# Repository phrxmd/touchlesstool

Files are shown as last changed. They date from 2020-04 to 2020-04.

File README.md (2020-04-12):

# touchlesstool

A customizable, parametric 3D design for a "truly touchless" no-touch
tool, designed to allow opening doors, pushing buttons etc. without
coming into direct physical contact with the surfaces. The tool is
"truly touchless" in the sense that the tool itself, which potentially
could be contaminated with material from the surfaces it touches, is
normally hidden in a sleeve and protected from accidental touches by the
user.

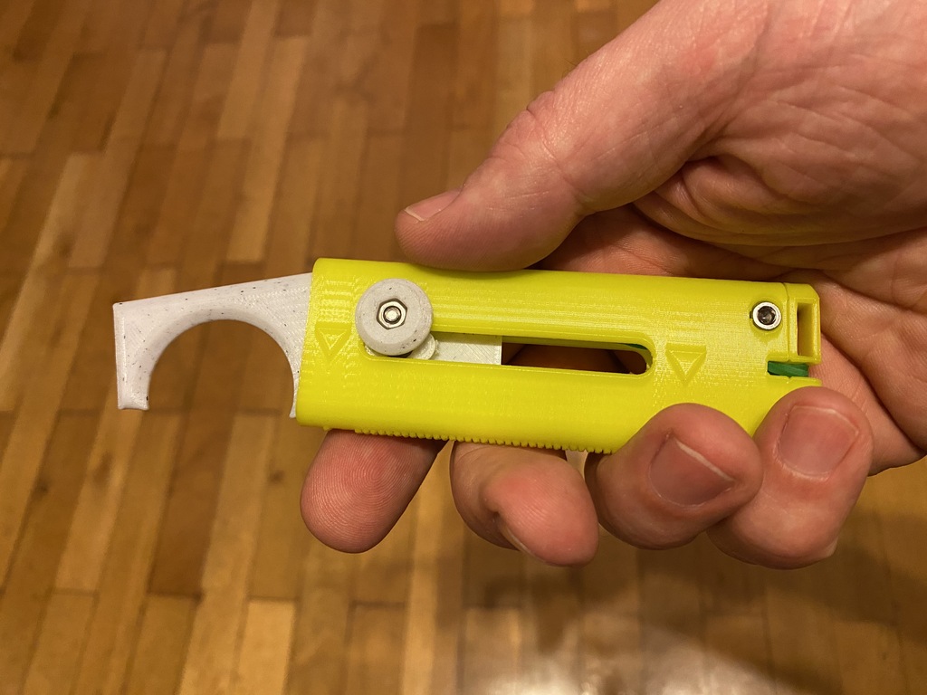
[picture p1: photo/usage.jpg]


The model is almost totally parametric, so you can change everything -
make it taller or wider, change some functionality, use different means
of attachment, generate different quality - by changing variables in the
SCAD file.

STLs for printing can be found in the `stl` subdirectory, on Thingiverse
(<https://www.thingiverse.com/thing:4266457>) and on PrusaPrinters
(<https://www.prusaprinters.org/prints/28714-truly-touchless-parametric-no-touch-tool>).

# Usage, printing and assembly

## Usage

Use the tool to open doors, push buttons or pick-up objects without
touching them with your hand. Extend the tool by pushing the knob with
your fingers. You can lock the tool in its extended state by moving the
knob sideways into the diagonal slot.

In daily use, you can attch the tool to your pants, belt or pocket using
a lanyard or an extensible "badge yo-yo". The end cap has a slot for
attaching it.

The tool should offer the user some protection against accidental touch
infection by means of its design. However, users may want to disinfect
it. For disinfection, the tool blade can be rinsed in alcohol or any
sterilizing liquid, or wiped off with a suitable substance, depending on
your context. If you want to be able to sterilize the tool, make sure to
print it with a material that quite literally can take the heat. Common
materials like PLA and PETG are not heat-resistant enough.

## Printing

The model is quite print-friendly in the default configuration. There
are no great overhangs or structures that require support - the longest
is a 10mm slot in the endcap. The tool sleeve should be printed
standing, so it may require some adhesion structures (like a brim or
raft). I usually print the sleeve on a raft, and the other structures
"as is".

Recommended print settings are: layer height 0.2, infill 25-30%, infill
pattern "cuboid" (in Cura) or something similar that gives rigidity in
all directions, and whatever temperature and flow settings match your
filament.

## Assembly of printed parts

In the default configuration, assembly requires the following parts:

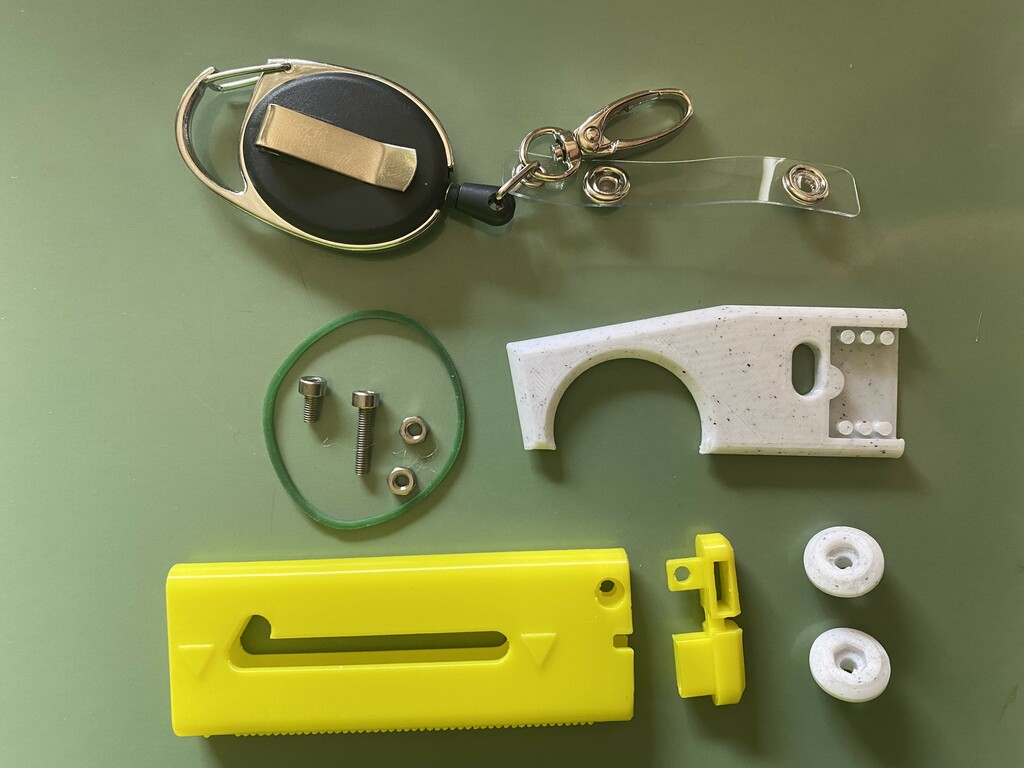
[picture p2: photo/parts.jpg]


1.  Printed parts
    1.  Printed tool body (with the hook and central bolt hole)
    2.  Printed sleeve (with the central slot)
    3.  Printed endcap
    4.  Printed bolt
2.  Other parts ("vitamins" in RepRap parlance)
    1.  Two bolts M3x6 and M3x14 (or minimally longer).
    2.  Two hex nuts.
    3.  A rubber band (short-ish is better).
3.  Optional parts
    1.  A lanyard or "badge yo-yo" for attaching the tool to your belt
        or pocket.

These are the steps for assembly:

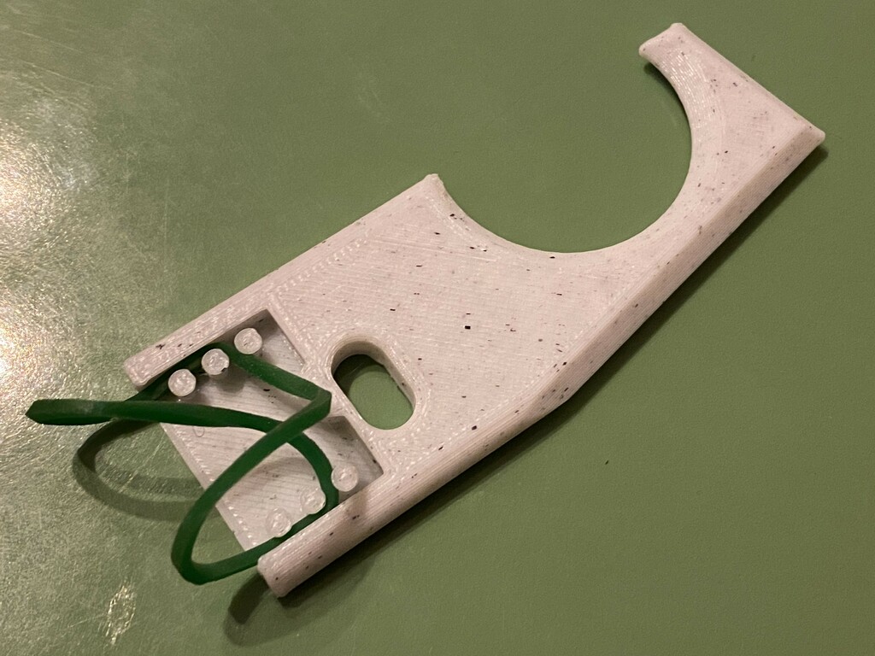
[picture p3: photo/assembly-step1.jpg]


Thread the rubber band into the body on both sides. The body has a
cavity at the bottom with rows of posts that are meant for this purpose.
Find a configuration where your rubber band extends in at least one loop
below the body for 1-2 cm (not longer).

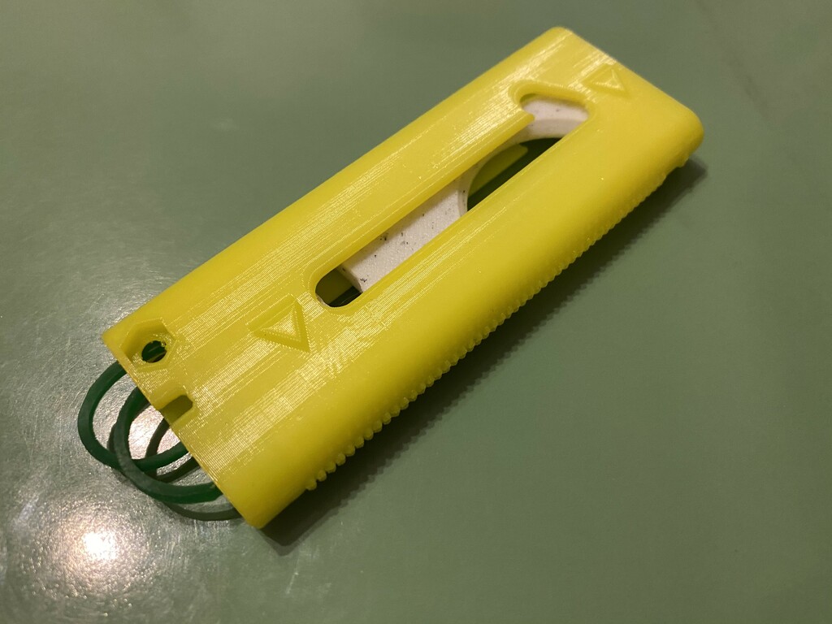
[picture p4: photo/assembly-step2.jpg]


Thread the body and rubber band into the sleeve from the top. The sleeve
has raised triangles above and below the slots; this is the direction
where the tip of the tool should point. Then pull the loop end of the
rubber through the bottom of the sleeve. Use a paperclip or similar if
it gets fiddly, which it probably will.

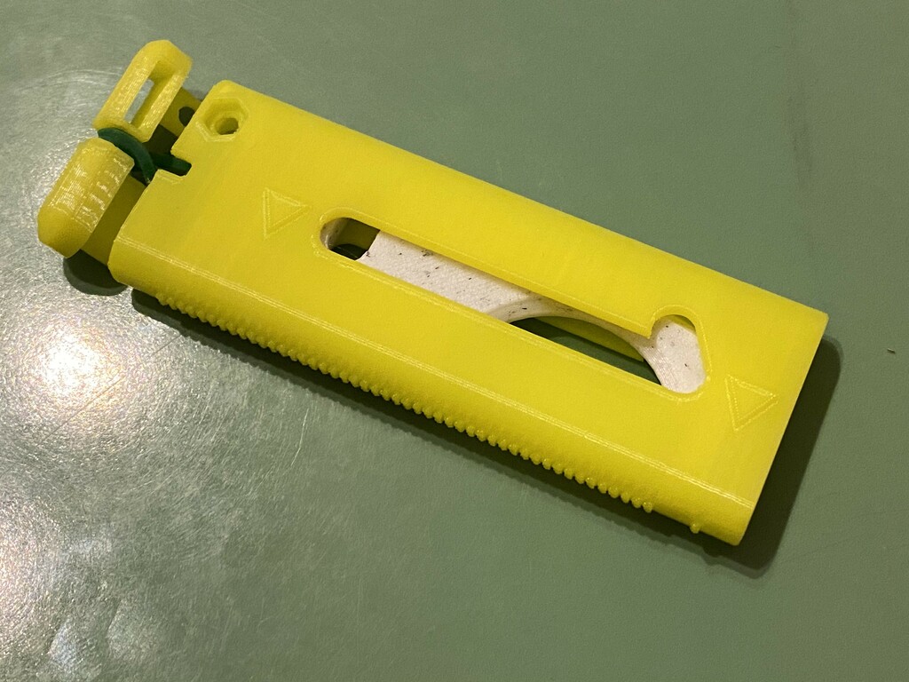
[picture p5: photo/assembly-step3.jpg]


Put the end cap into the rubber loop so that the rubber strands run in
the groove around the endcap, and attach the endcap to the sleeve. It
should sit snugly, and the rubber should not be too loose. Screw the
endcap into the body using an M3x6 bolt and a hex nut.

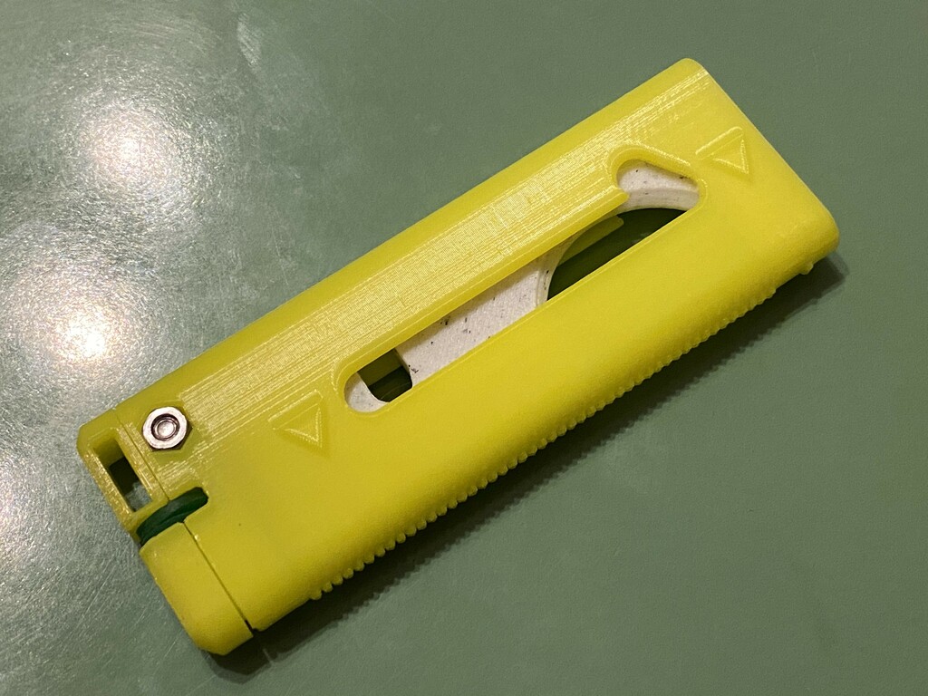
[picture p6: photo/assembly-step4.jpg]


Insert an M3x14 bolt and hex nut into the two parts of the printed
central bolt, and attach them through the central hole.

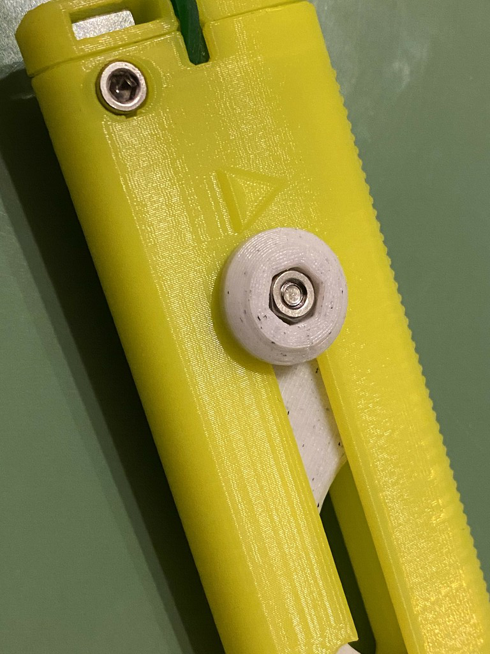
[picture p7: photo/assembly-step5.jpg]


(optional) Thread your lanyard through the slot in the endcap.

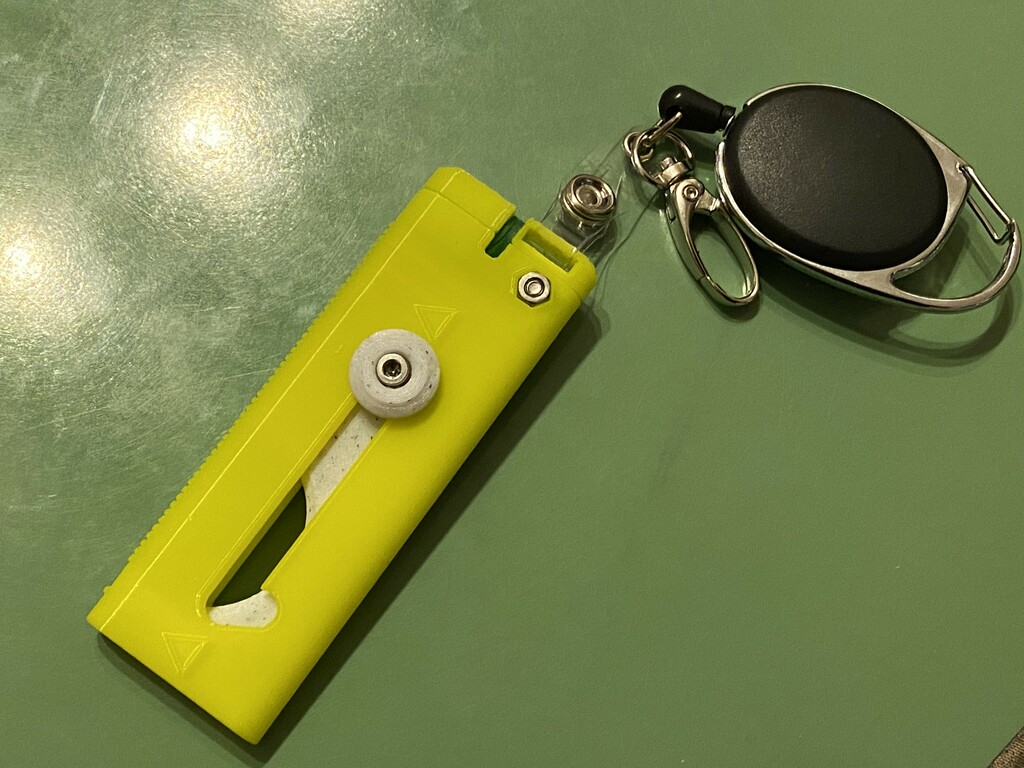
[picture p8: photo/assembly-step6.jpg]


That's it\!

# Customization

The model was written in SCAD and is parametric and highly customizable.
It is designed with 3D printing in mind. Open it in
[OpenSCAD](https://www.openscad.org) to see the configuration options
and generate STL files for printing.

## Common customization use cases

In the default configuration, the model generates an STL file with all
the parts for a tool that is about 9.5 by 3.5 by 1 cm, held together by
M3 bolts.

### Generating only some parts, or separate parts

This is a FAQ item. In the SCAD file, there are a set of configuration
items in the beginning that allow you to specify which parts of the
model to generate. You can set them to `true` one by one to generate
STLs for the parts you need.

### A model with no lanyard slot, or with a hole for a keyring

Set `ATTACHMENT_STYLE` to `none` or `hole` instead of the default
`slot`. The diameter of the keyring hole is set by `CAP_HOLE_DIA`, the
default is 5mm. If you add a keyring hole, you might also need to
increase `CAP_HEIGHT` and/or lower `CAP_CHAMFER`, to make sure that the
cap is big enough to hold the key ring securely.

### A model that works without bolts

If you prefer to glue the model together, and would like to do without
bolts, change the following:

  - Set `CAP_SCREW` to false. This will remove the screw hole in the
    sleeve and will generate a shape for the endcap that is more
    suitable for glueing.
  - Set `SCREW_DIA`, `SCREW_HEAD_DIA` and `SCREW_NUT_DIA` to zero. This
    will generate a bolt without a screw hole.
  - If you want to glue the bolt together, the best bolt type
    (`BOLT_TYPE` variable) is probably `chicago`. This will generate a
    sleeve bolt with an inner and outer part. Glue the inner into the
    outer bolt for a reasonably strong connection.
  - If you are really worried about the strength of your bolt, you can
    set the `BOLT_TYPE` variable to `halves`. This will split the bolt
    in half and place the halves flat on the print bed. You will have to
    glue them together, but with this placement the layer direction will
    be longitudinal to the bolt, resulting in much better shear
    strength.

### A model that works with an existing Chicago bolt

If you have a metal Chicago bolt (e.g. with 6mm diameter), like in Elwin
Alvarado's original model, do the following:

  - Set `BOLT_TYPE` to `knob`, this should generate only the knob with
    no bolt.
  - Set `SCREW_DIA` to the diameter of your bolt.
  - Set `SCREW_HEAD_DIA` and `SCREW_NUT_DIA` to the diameter of your
    bolt's head, and `SCREW_HEAD_FACES` and `SCREW_NUT_FACES` to a high
    value (e.g. 50), ssuming that your bolt head is round.
  - Set `SCREW_HEAD_DEPTH` and `SCREW_NUT_DEPTH` to the thickness of
    your bolt's head.

If the diameter of your Chicago bolt is not 6 mm, but something else,
set `HOLE_DIA` to the diameter of your bolt.

### A model that works with just an ordinary bolt, instead of a fancy printed one

If you want to use an ordinary bolt (e.g. M3x14 or M3x16) in place of a
printed bolt, set `HOLE_DIA` to the diameter of your bolt with some
reserves - e.g. 3.6 for an M3 bolt - and follow the instructions for the
existing Chicago bolt above. Remember to keep the `SCREW_NUT_FACES`
value to 6 if you want to secure the bolt with an ordinary captive hex
nut.

The advantage of this scenario is that the slot is narrower, so that
there is less possibility to accidentally touch something inside. Note
that this is still quite an elusive scenario. However, this kind of
attachment is not recommended, because the knob will slide along the
body and will be hard to extend, and because the sleeve material will
suffer from repeated snapbacks of the bolt threads moving up and down
the sleeve.

### A model with a longer sleeve, so that the hook is hidden inside when retracted

The rationale behind a longer sleeve is that with the default length,
you can still see the hook through the slot, and there is a small but
nonzero probability that your hands might get in touch with infected
material on the hook that way. If you make the sleeve longer, the
potentially contaminated parts of the hook are above the side slot, so
you can't touch them.

In this case, set `BODY_LENGTH` to a higher value - e.g. 120 instead of
80 if you leave the hook size otherwise unchanged.

In addition, set `EDGE_EXTEND` to a higher value, because with the
longer tool, otherwise the diagonal cutoff cuts off more of the back
edge. Instead of the default 0.98, a value such as 1.2 is a good idea.

### A model with a thicker sleeve

Set `SLEEVE_THICKNESS` to a higher value, e.g. 3mm instead of the
default 1.5. You might also need to check the height and chamfer of the
endcap to make sure that it still looks good.

## Overview of customization options

For a detailed overview of customization options, see the source code,
it has documentation built in. You can customize pretty much everything
in terms of dimensions and functionality.

# Common questions and to-do list

## FAQ

### I need separate STLs for the parts.

Go to the beginning of the SCAD file and set the `GENERATE_BODY`,
`GENERATE_SLEEVE`, `GENERATE_ENDCAP` and `GENERATE_BOLTS` to generate
only those parts that you need.

### Rendering in OpenSCAD is really slow\!

That is true. The main culprit here is that most edges in the model are
chamfered. This looks and feels nice in the printed object, but it
generates lots and lots of little polygons around every edge that take
long to render.

Another culprit is the "roundness" of the rounded parts - in OpenSCAD
this is the `$fn` setting.

You can remove the chamfering, and stick to the default roundness, by
customizing the model and setting the `CHAMFER` and `ROUND_CIRCLES`
variables in the beginning of the customization section to `false`.

### Compiling the design in OpenSCAD gives an error message about aborting normalization\! (Also: I get assertion errors in OpenSCAD\!)

Same as above. The model is a bit taxing on OpenSCAD's rendering. When
making changes to the model, best set `CHAMFER` and `ROUND_CIRCLES` to
`false` for the time being. That should reduce the complexity enough to
work in a normal OpenSCAD compilation workflow. Then set them back to
`true` when exporting STLs. (In an earlier version of the model, these
variables were called `WORK_IN_PROGRESS`.)

In spite of whatever messages you see during compilation and rendering,
the model should render fine (F6 in OpenSCAD). I tested it using
OpenSCAD 19.01 (in Ubuntu) and 19.05 and it works on both.

## To do

  - The tool currently cannot be used well with capacitive touchscreens.
    You could try to print it in a conductive material, or integrate
    some wires into the tip. Older (resistive) touchscreens do work
    somewhat better.

# Version history

  - v0.1: Initial design based on SCAD adaptation of Elwin Alavarado's
    original idea. Added rubber band fixture v1: vertical slot, ring
    around bolthole
  - v0.2: Added bolt to model; rubber band fixture v2: round hooks on
    front and back (slips too easily)
  - v0.3: Added lanyard slot to endcap; rubber band fixture v3: hooks on
    the left and right (too strong)
  - v0.4: Horizontal locking slot; screw-through bolt design; rubber
    band fixture v4: open space with rubber band posts
  - v0.5: Diagonal locking slot for easier printing; added screw hole to
    endcap
  - v1.0: First published version
  - v1.1: Added keyring hole to endcap, based on [this
    idea](https://thingiverse.com/thing:4275480) by [Matt
    Bordoni](https://www.thingiverse.com/matador/about), fixed a few
    bugs
  - v1.2: Added debugging for parts placement below Z

# Attribution and license

The original idea comes from a non-parametric Fusion 360 design by Elwin
Alvarado [published
here](https://www.prusaprinters.org/prints/27210-truly-touchless-no-touching-multi-toolhook)
on PrusaPrinters. Used with permission.

The GitHub repository for this model is
<https://github.com/phrxmd/touchlesstool>.

(C) 2020 Philipp Reichmuth. Published under the Creative Commons
Attribution-ShareAlike 4.0 International license (see
[LICENSE.md](LICENSE.md)).

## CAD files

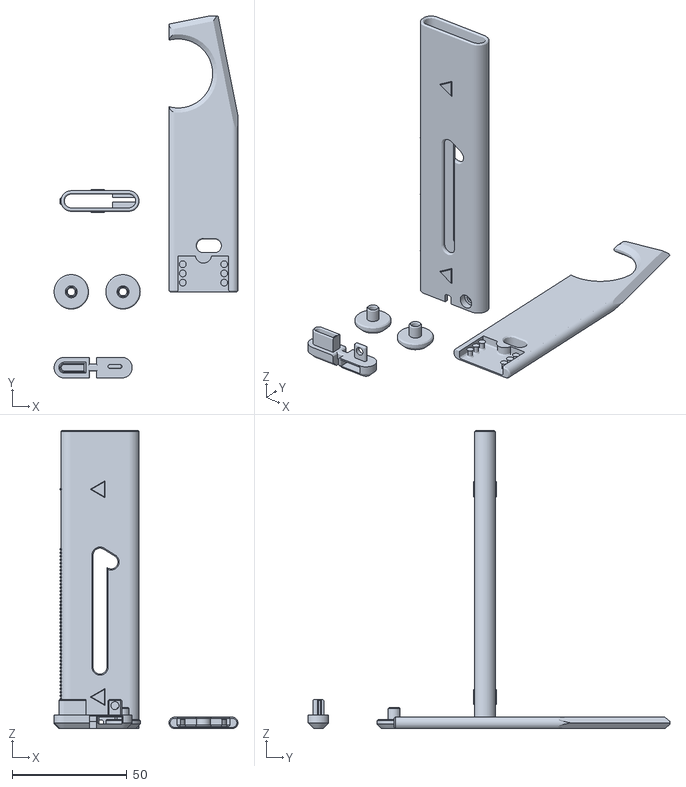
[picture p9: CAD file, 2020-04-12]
stl/touchlesstool-6mm-LONG-allparts.stl
80.0 x 157.5 x 129.8

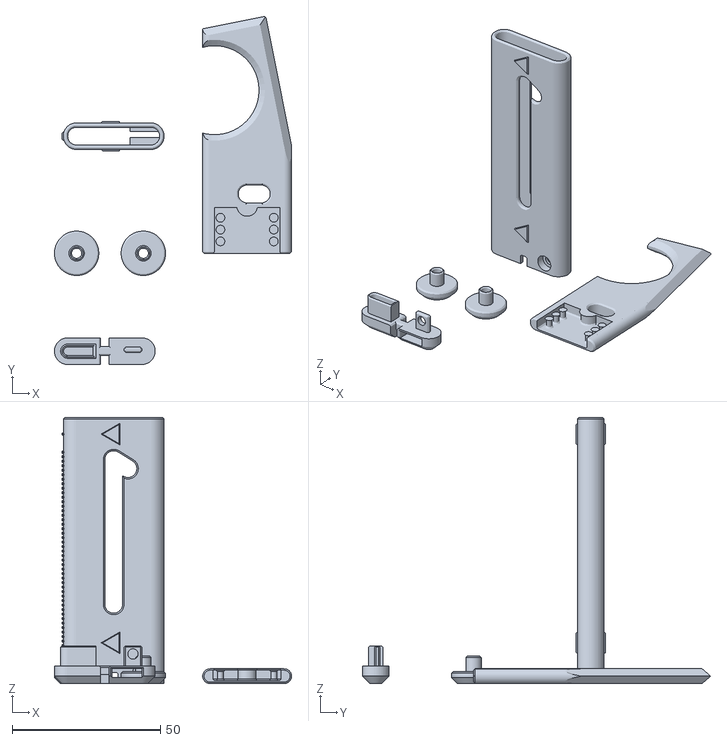
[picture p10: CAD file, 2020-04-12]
stl/touchlesstool-6mm-allparts.stl
80.0 x 117.4 x 89.8

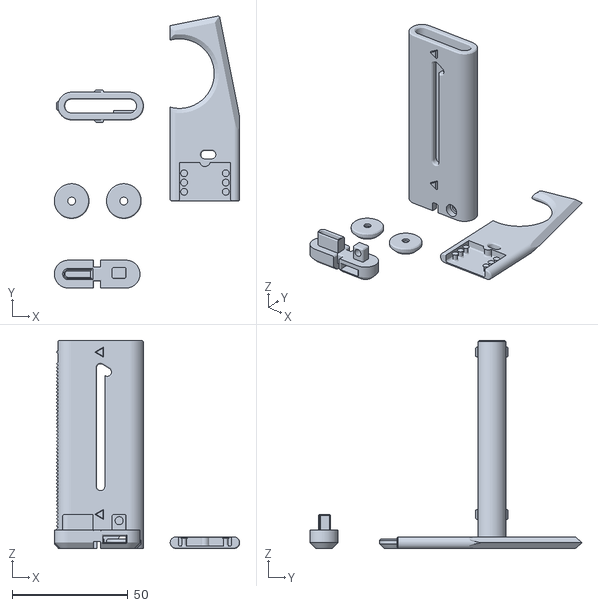
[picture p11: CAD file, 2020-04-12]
stl/touchlesstool-3.6mm-MAXSEC-allparts.stl
80.0 x 117.4 x 89.8

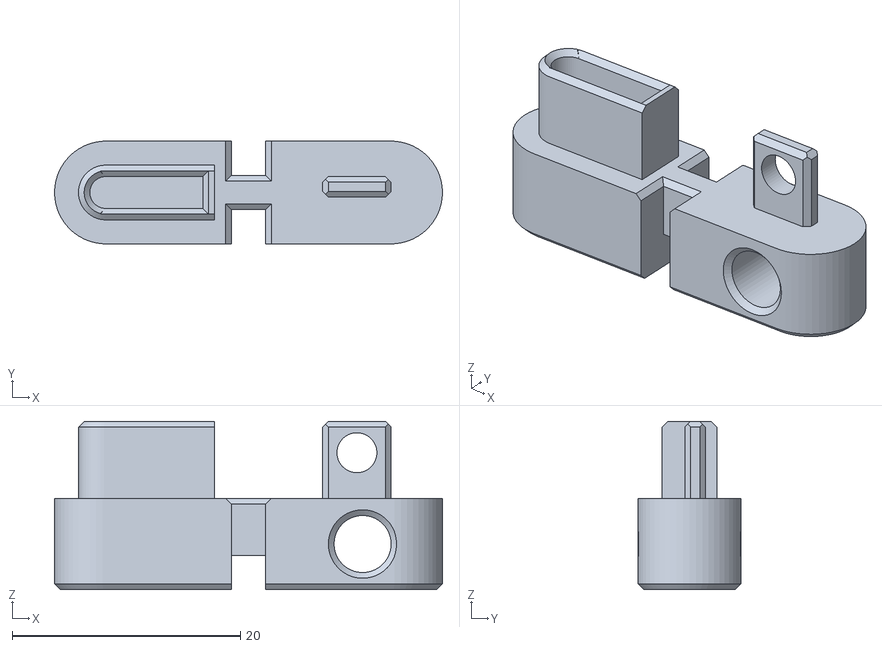
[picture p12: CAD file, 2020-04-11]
stl/touchlesstool-6mm-endcap-keyring.stl
34.0 x 9.00 x 14.8

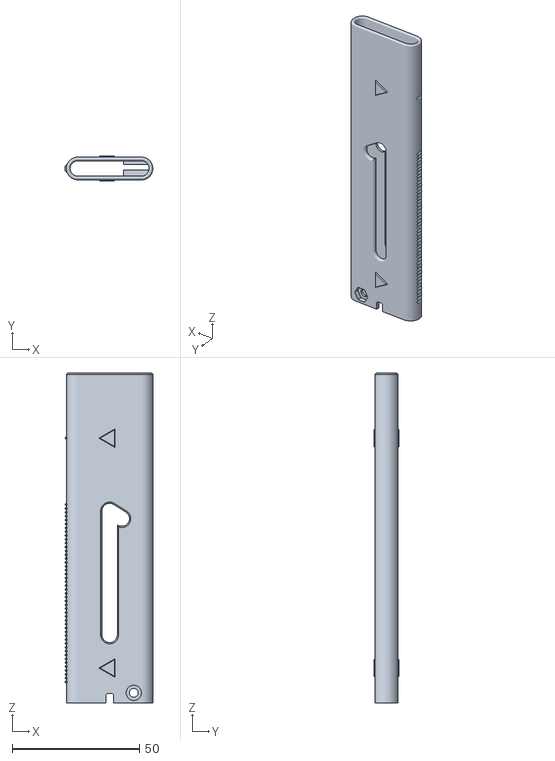
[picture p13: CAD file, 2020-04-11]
stl/touchlesstool-6mm-LONG-sleeve.stl
34.5 x 10.0 x 129.8

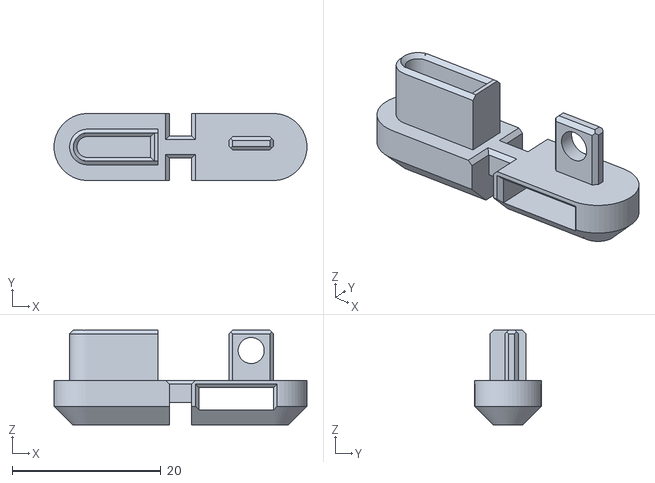
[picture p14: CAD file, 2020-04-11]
stl/touchlesstool-6mm-endcap.stl
34.0 x 9.00 x 12.8

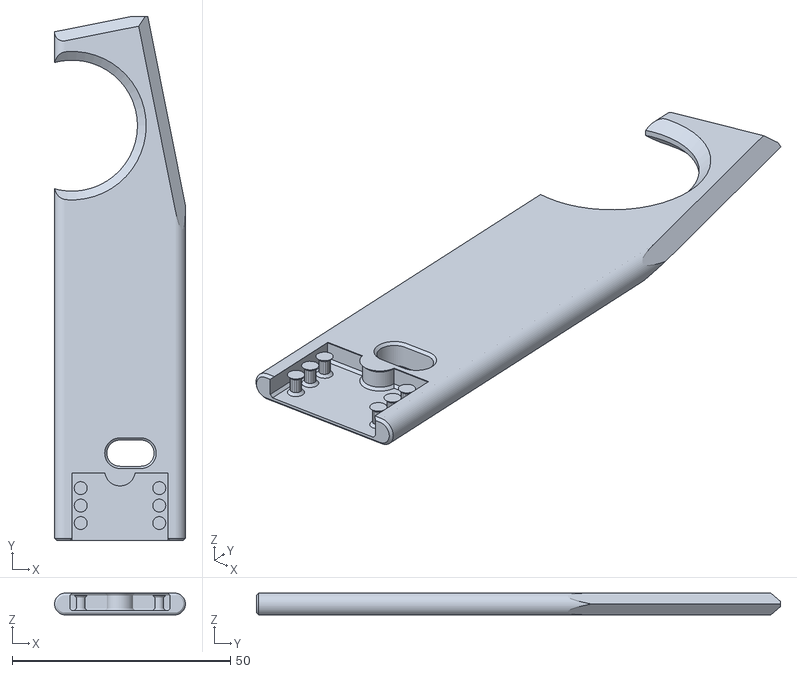
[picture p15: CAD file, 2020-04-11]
stl/touchlesstool-6mm-LONG-body.stl
30.0 x 120.0 x 5.00

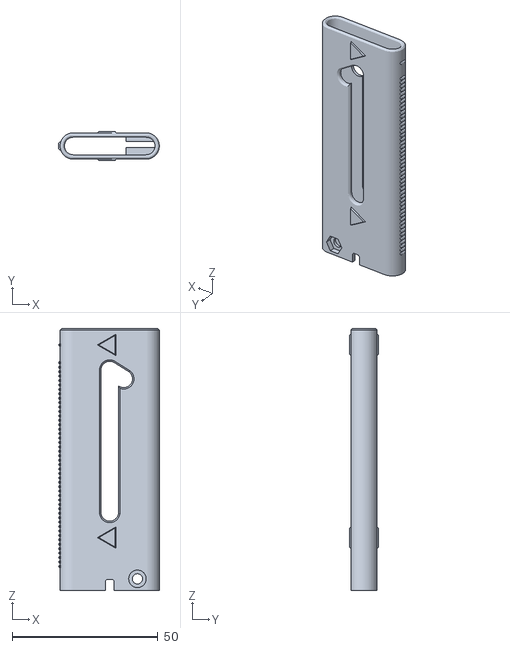
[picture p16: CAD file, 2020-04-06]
stl/touchlesstool-6mm-sleeve.stl
34.5 x 10.0 x 89.8

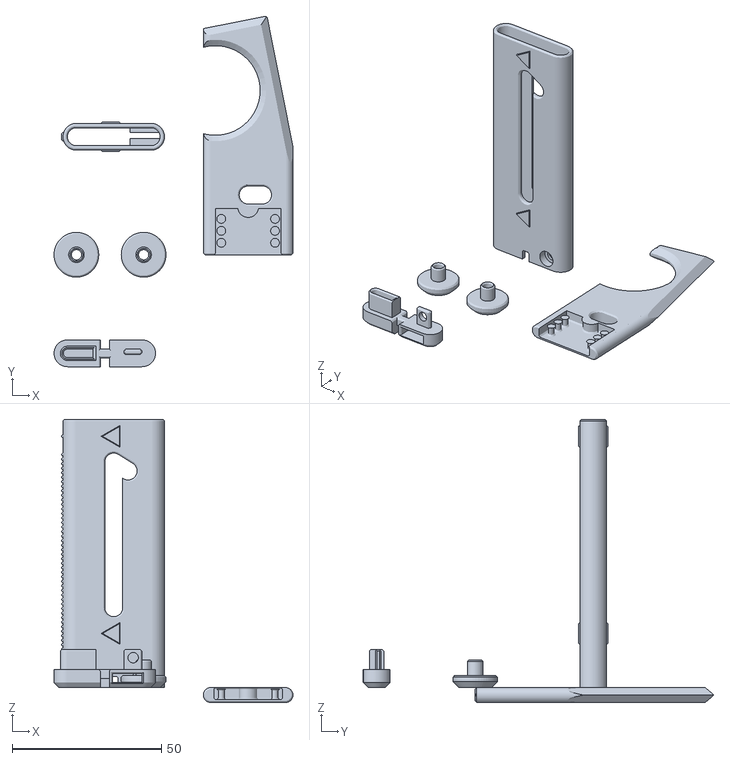
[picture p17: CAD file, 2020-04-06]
stl/touchlesstool-allparts.stl
80.0 x 117.4 x 94.8

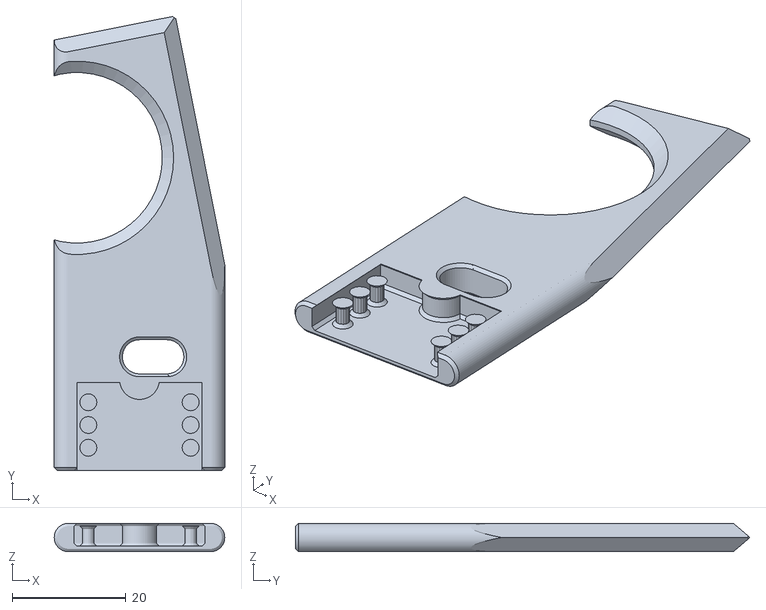
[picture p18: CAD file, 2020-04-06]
stl/touchlesstool-6mm-body.stl
30.0 x 79.9 x 5.00

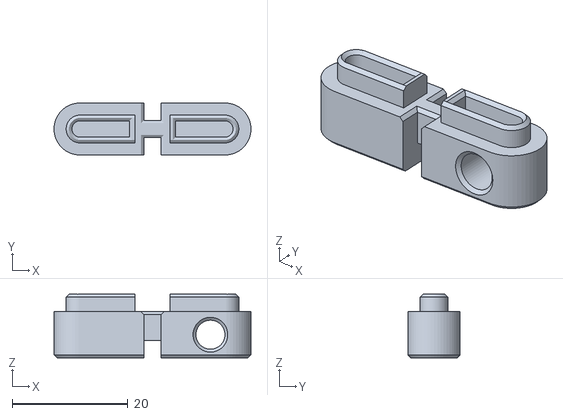
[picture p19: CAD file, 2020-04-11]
stl/touchlesstool-6mm-NOSCREW-endcap-keyring.stl
34.0 x 9.00 x 11.0

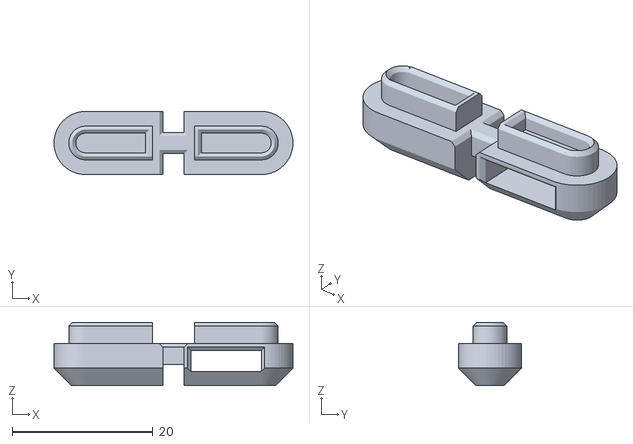
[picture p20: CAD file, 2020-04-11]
stl/touchlesstool-6mm-NOSCREW-endcap.stl
34.0 x 9.00 x 9.00

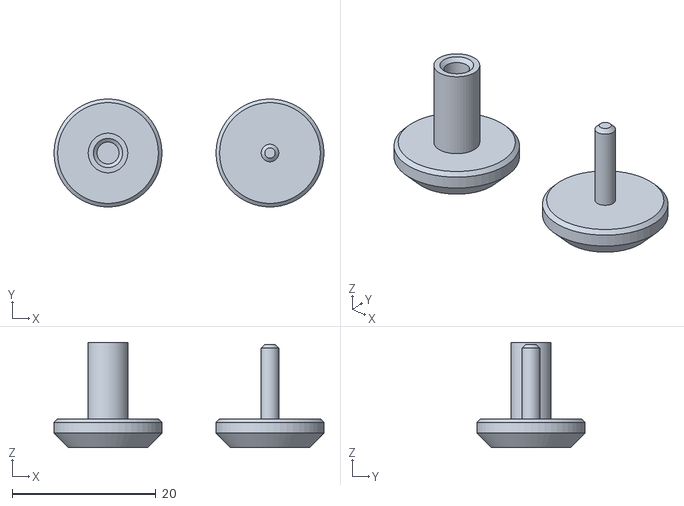
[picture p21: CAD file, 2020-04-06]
stl/touchlesstool-6mm-NOSCREW-bolts.stl
37.5 x 15.0 x 14.6

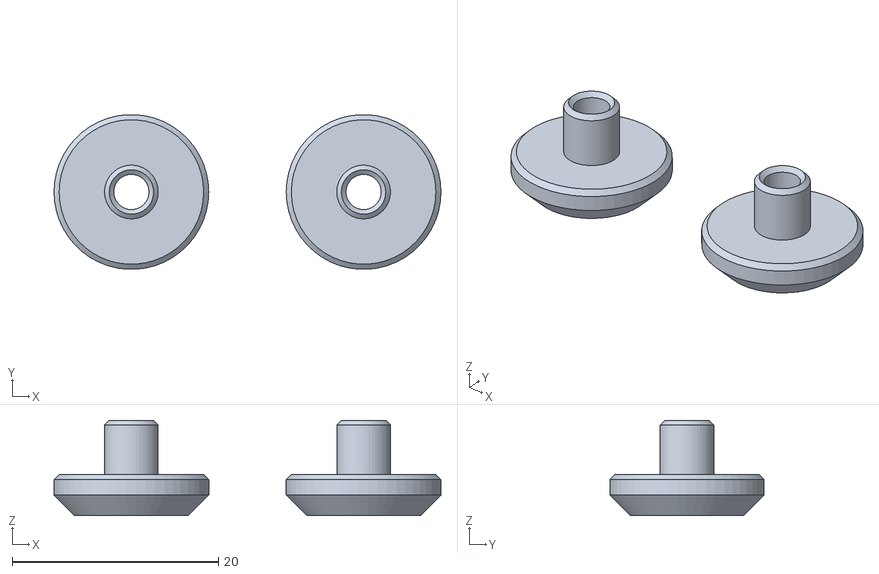
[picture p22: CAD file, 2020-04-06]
stl/touchlesstool-6mm-bolts.stl
37.5 x 15.0 x 9.25

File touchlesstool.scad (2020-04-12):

/** "Truly touchless" parametric no-touch tool
  * 
  * Designed to open doors, push buttons, pick up bags etc.
  * without touching them, and (importantly) without touching the surfaces
  * that do touch them ("no-touch"). The actual tool body is hidden
  * in a sleeve, can be extended with a knob and locked in place. The tool
  * itself consists of a hook, two points at somewhat different angles,
  * a short straight front section and a larger straight back blade.
  *
  * The 3D model consists of four parts:
  * - tool body (with hook and points ),
  * - tool sleeve (with slot for sliding it in and out),
  * - end cap (for closing it at the bottom, possibly attaching
  *   the tool body to the sleeve with a rubber band to let it
  *   snap back;
  * - knob to move it in and out, optionally with sleeve bolt to 
  *   hold it together.
  *
  * Shape and dimensions are parametric and widely customizable. 
  * In fact, maybe *too* customizable - some of the more exotic options 
  * generate strange behaviour in OpenSCAD (see comments), and I don't
  * expect this to work well in Thingiverse Customizer etc. as it gets quite
  * resource-heavy.
  *
  * Known bugs and todos:
  * - The model triggers a few bugs in OpenSCAD where assertions are thrown,
  *   but it doesn't seem to impact the output.
  * - OpenSCAD complains about the sleeve not being a valid 2-manifold.
  *   The output is a valid STL, however.
  *
  * Todos:
  * - Figure out a way to use the tool with capacitive touchscreens (ATMs etc.)
  *   Maybe some wires in the tool tip?
  * 
  * Original non-parametric design by Elwin Alvarado,
  * https://www.prusaprinters.org/prints/27210-truly-touchless-no-touching-multi-toolhook
  * Used with permission
  * 
  * (C) 2020 Philipp Reichmuth, CC-BY-SA 4.0
  *
  * Version history:
  * v1.2: Added debugging for parts placement below Z.
  * v1.1: Added keyring hole to endcap, fixed a few bugs
  * v1.0: First published version
  * v0.5: Diagonal locking slot for easier printing; added screw
  *       hole to endcap 
  * v0.4: Horizontal locking slot; screw-through bolt design; rubber band 
  *       fixture v4: open space with rubber band posts
  * v0.3: Added lanyard slot to endcap; rubber band fixture v3:
  *       hooks on the left and right (too strong)  
  * v0.2: Added bolt to model; rubber band fixture v2: round hooks
  *       on front and back (slips too easily)
  * v0.1: Initial design based on SCAD adaptation of Elwin Alavarado's
  *       original idea. Added rubber band fixture v1: vertical slot,
  *       ring around bolthole
  */

/* [Model generation settings] */

// Chamfer most edges.
// This gives a great improvement in appearance, and some
// in functionality (e.g. added stability for concave edges
// and rubber band slots), but adds LOTS of little polygons. 
// It may break F5 preview in OpenSCAD. 
// F6 rendering and F7 export should be fine, even if OpenSCAD
// occasionally throws assertions.
CHAMFER_EDGES = true;
CHAMFER = CHAMFER_EDGES ? 0.5 : 0; 

// Round off all circles. Warning: $fn values over ~20 get 
// expensive, especially with chamfering enabled. F5 preview 
// will be slow or may break due to the number of polygons.
// F6 rendering and F7 export will be fine.
ROUND_CIRCLES = true;
$fn=(ROUND_CIRCLES) ? 50 : $fn;

// Which models to generate
GENERATE_BODY   = true;
GENERATE_SLEEVE = true; 
GENERATE_ENDCAP = true;
GENERATE_BOLTS  = true;

// Debugging of basic forms
GENERATE_BODY_FORM = false;
GENERATE_SLOT_FORM = false;

// Debugging of parts placements
// See if there are parts extending below the build plate.
TEST_BELOW_Z = false;
// Trim any parts that extend below the build plate.
// This can happen in the STL export due to rounding errors
// in the various transformations. However, it also has the
// potential to damage your objects if the amounts are non-
// infinitesimal, so better test with TEST_BELOW_Z first.
TRIM_BELOW_Z = false;

/* [Tool shape] */

// Basic shape of the tool itself
BODY_WIDTH    = 30;
BODY_DEPTH    = 5;
BODY_LENGTH   = 80; // LONG: 120;
MIN_BODY_WALL = 1;      

// Hook at the end of the tool
HOOK_RADIUS        = 15;
// Move inward slightly, to give a <90% angle at the edge 
// for gripping
HOOK_CENTER_OFFSET = 4;
// Hook position measured from the *end* of the tool
HOOK_POS           = 25;
// How far the bottom edge of the hook should "stick out" 
// of the sleeve when fully extended
HOOK_STICKOUT      = 5;
// Hook blade shape: BODY_DEPTH/2 gives a sharp 45° edge,
// lower values leave a flat portion in the inner part of 
// the hook, and setting it to CHAMFER gives a flat edge with 
// the same amount of chamfering as anywhere else.
// Rationale: the sharper the edge, the smaller the contact
// surface - but an overly sharp edge may make it difficult 
// to use the tool to pick up heavier things; e.g. plastic 
// bags may tear).
HOOK_CHAMFER = BODY_DEPTH * 0.4;

// Angle of the top and rear edge
EDGE_ANGLE  = 11.25;
// Extend back edge if the hook ends up too thin at larger angles
// or in longer bodies.
// Values <1 shorten it forward (make it slimmer), 
// values >1 extend it to the back
EDGE_EXTEND = 0.98; // e.g. 1.2 for LONG version
// Supplementary offset of the rear edge from the bottom
// for very long blades
EDGE_OFFSET = 40;
// Tool back blade shape: BODY_DEPTH/2 gives a sharp edge,
// lower values leave a flat portion at the back of the blade,
// and setting it to CHAMFER gives a flat edge with the same 
// amount of chamfering as anywhere else.
// Rationale: the sharper the edge, the smaller the contact
// surface.
EDGE_CHAMFER = BODY_DEPTH/2;

// Diameter of the central bolt hole
HOLE_DIA = 6; // 3.6 for MAXSEC version with M3 bolts, otherwise 6mm
// Bolt hole position, measured from the bottom of the tool
HOLE_POS = 20;

/* [End cap] */

// Chamfer the bottom to round it of a little bit. 
// BODY_DEPTH/3 or BODY_DEPTH/2 gives an ergonomically nice form.
// Setting it to CHAMFER will apply the same chamfer as everywhere.
CHAMFER_CAP   = BODY_DEPTH/2; // CHAMFER; 

// Fixture for attaching the end cap through something
// - none: no fixture
// - slot: a rectangular slot
// - hole: a circular hole
ATTACHMENT_STYLE = "slot";
// Slot through end cap for a lanyard: width and height
CAP_SLOT_WIDTH  = 10;
CAP_SLOT_HEIGHT = 3;
// Hole through the end cap for attaching a key ring
CAP_HOLE_DIA    = 5;

// Fixing the end cap. Either rely on the rubber band,
// glue the end cap in, or add a screw.
CAP_SCREW = true; 
// Screw diameter - around 3.5 for M3
CAP_SCREW_DIA = 3.5;
// Diameter and depth of the groove for the cap screw
CAP_HEAD_DIA = 6;
CAP_HEAD_DEPTH = 3; // Leads to a very thin inner part, but better than nothing
CAP_HEAD_FACES = 50; // for a round hole
// Diameter and depth for the groove for the cap nut
CAP_NUT_DIA = 6.75;
CAP_NUT_DEPTH = 2;
CAP_NUT_FACES = 6; // for a hex nut
// Minimal thickness of material around the cap, nut and screws
CAP_SCREW_STANDOFF = 1;

// Height of the part of the end cap that slots into the sleeve
// If the cap is screwed in, this needs to be high enough to leave
// room for the screw.
// If the cap is glued in, this can be small (e.g. 3).
CAP_INSET     = CAP_SCREW 
                  ? 2*CAP_SCREW_STANDOFF+(CAP_HEAD_DIA)/2+CAP_SCREW_DIA/2
                  : 3; 
// Height of the actual end cap
CAP_HEIGHT = 6; // MAXSEC and thick-sleeve versions need more, maybe 8
// Minimal wall strength around cut-out slots
CAP_MIN_WALL  = 1; 
// Gap between end cap and sleeve for a snug fit
CAP_GAP       = 0.1;

// Calculated depth of screw blocks, needed for shaping the sleeve
// and endcap. Using the same calculated values here helps avoid errors
FRONT_SCREW_BLOCK=CAP_HEAD_DEPTH+CAP_SCREW_STANDOFF;
BACK_SCREW_BLOCK=CAP_NUT_DEPTH+CAP_SCREW_STANDOFF;

// Width of the rubber band slots in the sleeve and endcap
RUBBER_SLOT   = 3;
// Width of rubber fixtures inside the body part
RUBBER_GROOVE = 2;
// Height offset of rubber band posts inside the body, to lower them
// and protect them from slidingagainst the sleeve when opening/closing
RUBBER_STANDOFF = 0.5;

/* [Sleeve] */

// Extra sleeve length at the top, to avoid touching
// the tool when retracted
SLEEVE_OVERHANG  = 3;
// Sleeve should fit the tool body after the cap is inserted
SLEEVE_LENGTH    = BODY_LENGTH+SLEEVE_OVERHANG+CAP_INSET;
// Material thickness of the sleeve
SLEEVE_THICKNESS = 1.5; // MAXSEC: 3, otherwise 1.5  
// Gap between sleeve and tool: should move, but not wobble
SLEEVE_GAP       = 0.5;

// Put little triangles on the sides to point to the front
PLACE_TRIANGLES = true;
// How far the triangles should stand out
TRIANGLE_DEPTH = SLEEVE_THICKNESS/3;
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

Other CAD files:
stl/touchlesstool-6mm-endcap-noscrew.stl
stl/touchlesstool-6mm-NOSCREW-sleeve.stl
stl/touchlesstool-6mm-NOSCREW-bolts-robust.stl

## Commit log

2020-04-06 Added STLs for some common printed versions.
    [touchlesstool-6mm-body.stl, touchlesstool-6mm-bolts-noscrew-robust.stl, touchlesstool-6mm-bolts-noscrew.stl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]
2020-04-11 Added keyring hole, fixed a few bugs, extended README
    [touchlesstool-3.6mm-MAXSEC-allparts.stl, touchlesstool-6mm-LONG-allparts.stl, touchlesstool-6mm-LONG-body.stl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]
2020-04-12 Added debugging for below-Z placement, fixed STL files
    [touchlesstool-3.6mm-MAXSEC-allparts.stl, touchlesstool-6mm-LONG-allparts.stl, touchlesstool-6mm-allparts.stl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]
